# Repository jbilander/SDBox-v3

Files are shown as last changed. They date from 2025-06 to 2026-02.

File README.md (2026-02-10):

# SDBox-v3
A parallel to Pico 2 W and sd-card project for the Amiga

***

Firmware for this project with support for a blinking activity LED can be built from source here:<br />
https://github.com/jbilander/amiga-par-to-spi-adapter/tree/master/rp2350

***

<a href="images/SDBox-v3_pic5.png">
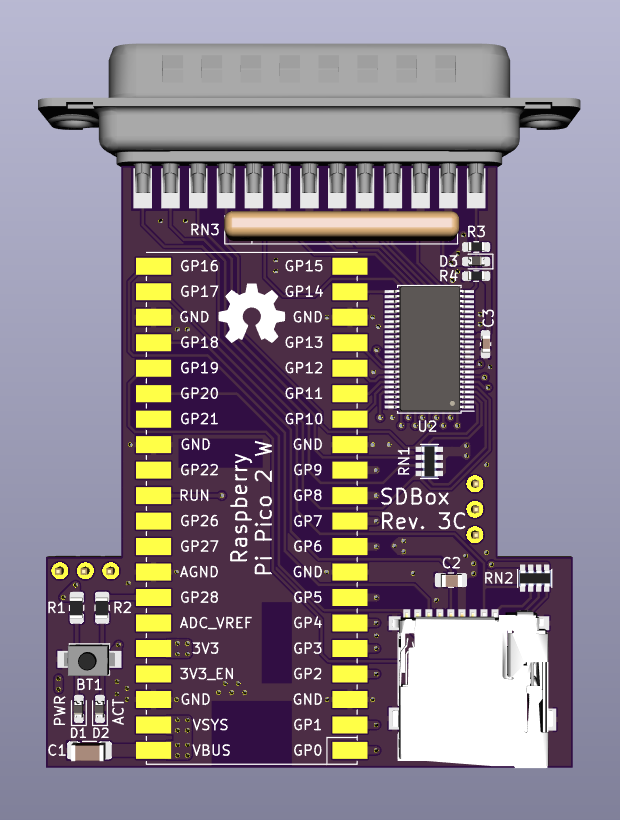
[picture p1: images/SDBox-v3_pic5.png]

</a>
<a href="images/SDBox-v3_pic6.png">
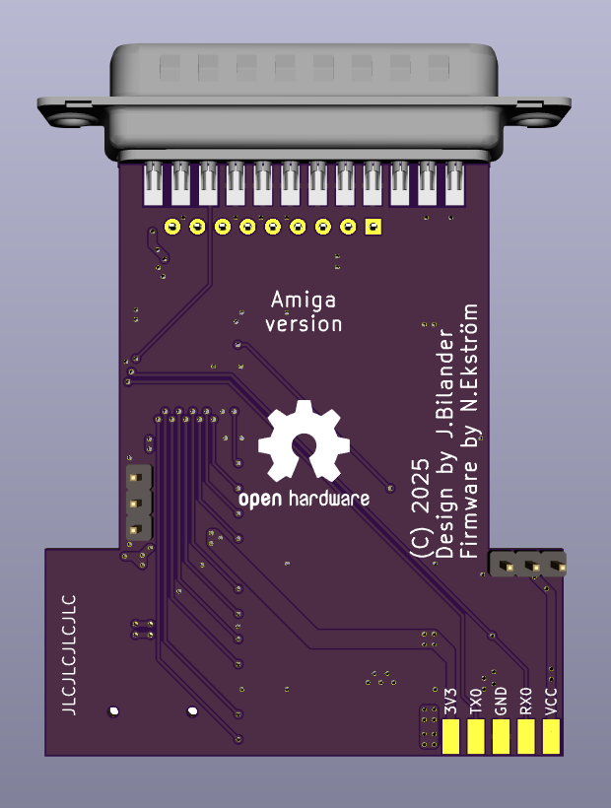
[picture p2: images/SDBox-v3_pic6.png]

</a>

***

<a href="images/SDBox-v3_pic1.jpg">
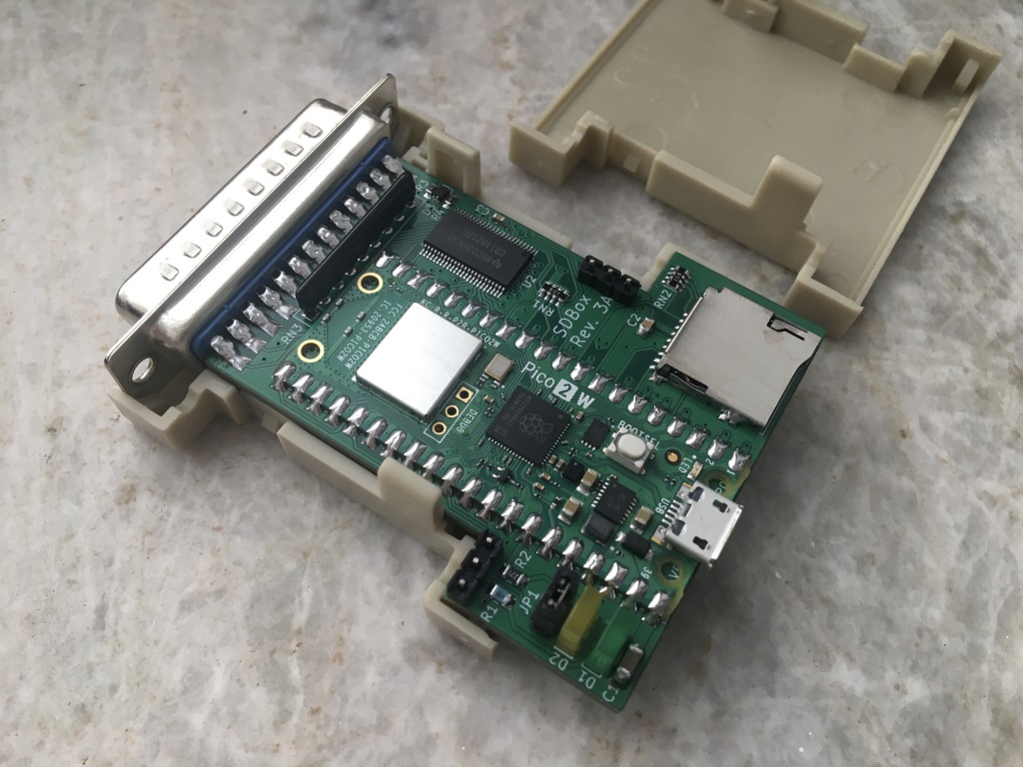
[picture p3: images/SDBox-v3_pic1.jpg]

</a>

***

<a href="images/SDBox-v3_pic2.jpg">
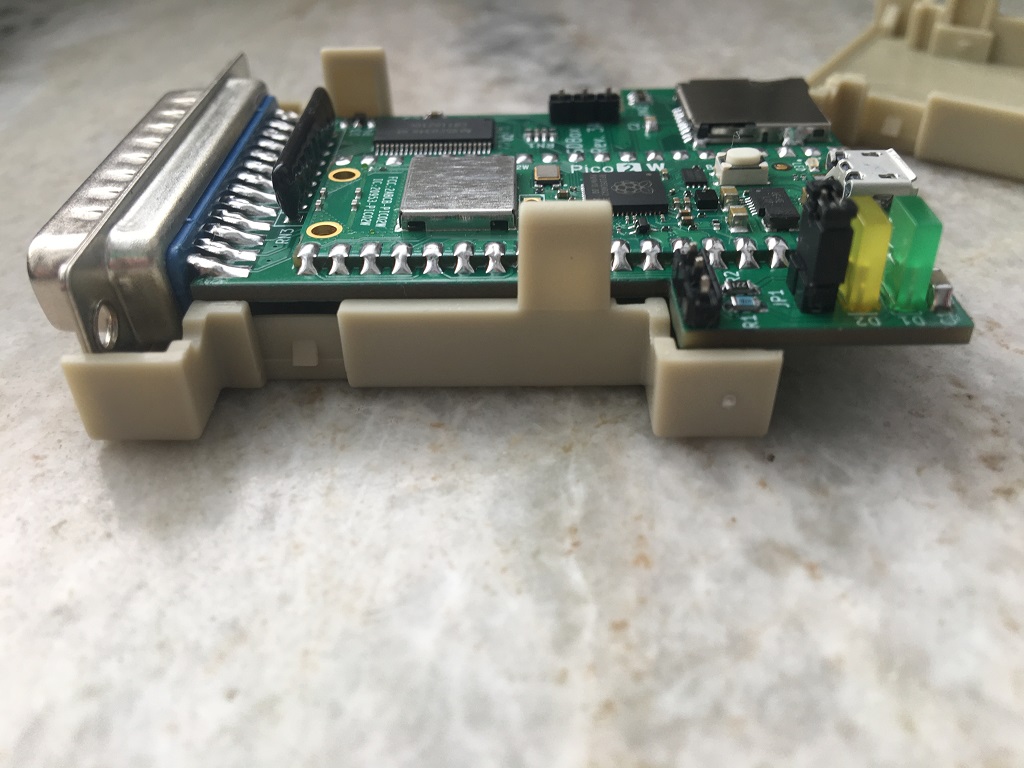
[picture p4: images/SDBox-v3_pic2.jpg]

</a>
<a href="images/SDBox-v3_pic3.jpg">
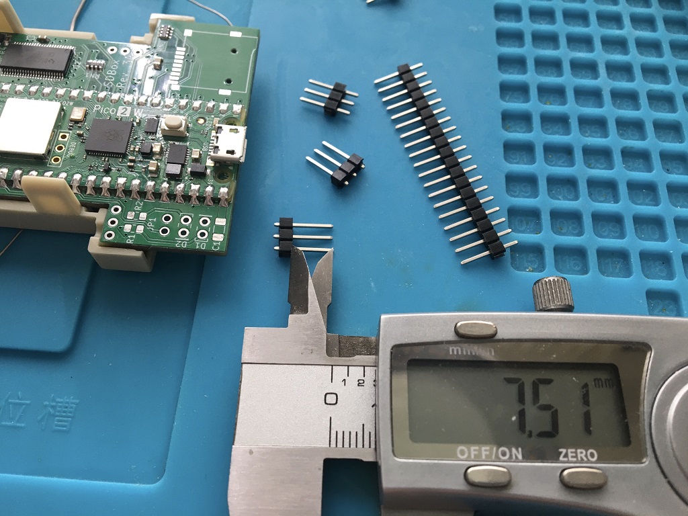
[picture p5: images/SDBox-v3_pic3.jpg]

</a>
<a href="images/SDBox-v3_pic4.jpg">
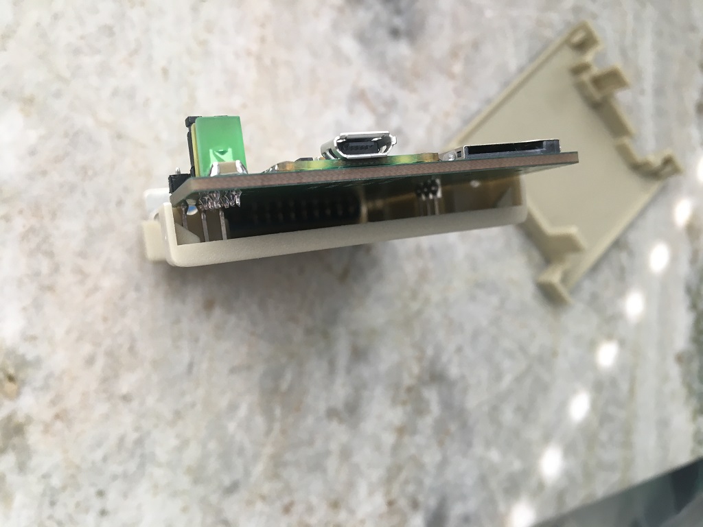
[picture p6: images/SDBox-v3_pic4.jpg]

</a>

***
BOM Rev. 3C
---------
same as 3B but with these changes:
Reference  | Name/Value   | Package | Notes
-|-|-|-|
BT1 | Push button | Sunrom_Tactile_Switch_3x4x2mm_SMD_2-Pin | [Aliexpress](https://www.aliexpress.com/item/4001107238344.html)
D1-D2 (Optional) | SMD LED | 0603 | [Aliexpress](https://www.aliexpress.com/item/1005003836509392.html)
R1 (Optional) | 1k Ω | 0805 | (Mandatory if D1 populated) Series resistor for D1 LED, adjust R-value to your type of LED and preferred brightness
R2 (Optional) | 1k Ω | 0805 | (Mandatory if D2 populated) Series resistor for D2 LED, adjust R-value to your type of LED and preferred brightness

***

BOM Rev. 3B
---------
Reference  | Name/Value   | Package | Notes
-|-|-|-|
U1 | Raspberry Pi Pico 2 W | SC1633 (without header) | [RPi Pico 2 W](https://www.mouser.com/ProductDetail/358-SC1633)
U2 | SN74CBT16210 | TSSOP-48 6.1x12.5mm_P0.5mm | 20-BIT FET Bus switch with level shifting, high-speed TTL-compatible. [SN74CBT16210CDGGR ](https://www.mouser.com/ProductDetail/595-SN74CBT16210CDGG)
J1 | DB25_Male | DSUB-25_Male_EdgeMount_P2.77mm| DB25 Male [Aliexpress](https://www.aliexpress.com/item/1005006354086316.html)
J2 | Sunrom Micro SD Card Holder | 9-pin Micro SD card slot connector | Sunrom Micro-SD [Aliexpress](https://www.aliexpress.com/item/32802051702.html)
J3 | (Optional) UART0 PinHeader | 5-pin 2.54 mm pitch single row | Optional 5V-tolerant header for UART0 (TX on GP12, RX on GP13) 
JP1 | (Optional) PinHeader/Jumper shunt | 2-pin 2.54 mm pitch single row | Jumper on connects Amiga /RESET signal together with RUN-pin (pin 30) on Pico 2 W, resets pico on Ctrl-A-A
D1 (Optional) | LED Square 2x5x7mm | PinHeader_1x02_P2.54mm_Vertical, pin pitch 2.54 mm | Power LED indicator [Aliexpress](https://www.aliexpress.com/item/1005006220921860.html)
D2 (Optional) | LED Square 2x5x7mm | PinHeader_1x02_P2.54mm_Vertical, pin pitch 2.54 mm | Activity LED indicator [Aliexpress](https://www.aliexpress.com/item/1005006220921860.html)
D3 | MMDL6050T1G Small Signal Switching Diode 200mA | SOD-323 | [MMDL6050T1G](https://www.mouser.com/ProductDetail/863-MMDL6050T1G)
R1 (Optional) | 4.7k Ω | 0805 | (Mandatory if D1 populated) Series resistor for D1 LED, adjust R-value to your type of LED and preferred brightness
R2 (Optional) | 220 Ω | 0805 | (Mandatory if D2 populated) Series resistor for D2 LED, adjust R-value to your type of LED and preferred brightness
R3 (Optional) | 10k Ω | 0603 | Pull-up for /STROBE signal, not currently used
R4 | 2.9k - 3k Ω | 0603 | Resistor for dummy loading D3 to achieve steady 0.6-0.7V VCC drop resulting in ~4.3V power supply to U2 [CR0603-FX-2941ELF](https://www.mouser.com/ProductDetail/652-CR0603FX-2941ELF)
RN1, RN2 | CAY16-103J4LF RES ARRAY 4 Resistors 10k Ω | 1206 | [CAY16-103J4LF](https://www.mouser.com/ProductDetail/652-CAY16-103J4LF)
RN3 | A103J | Bussed Resistor Network Array SIP-9 | Pull-up resistors for data lines, 9PIN-10K [Aliexpress](https://www.aliexpress.com/item/1005006954621214.html)
C1 | Capacitor 10uF | 1206 | 
C2 | Capacitor 0.1uF = 100nF | 0805 | 
C3 | Capacitor 0.1uF = 100nF | 0603 |
Housing | 2 x Plastic Shell Cover | For DB25 plug | [Aliexpress](https://www.aliexpress.com/item/1005004717091904.html)
2 x PinHeader | PinHeader Board Weight/Level Support | 3-pin 2.54 mm pitch single row | Move the plastic guard to leave ~7.5 mm of pin before soldering in order to hold board in perfect level

***

When ordering from JLCPCB select:

Specify Layer Sequence: Yes

    L1(Top layer):    F_Cu.gbr
    L2(Inner layer1): GND_Cu.gbr
    L3(Inner layer2): VCC_Cu.gbr
    L4(Bottom layer): B_Cu.gbr

Remove Order Number: 

    Specify a location

This will notify JLC where to put the order number, they will replace the "JLCJLCJLCJLC" silkscreen label.

***

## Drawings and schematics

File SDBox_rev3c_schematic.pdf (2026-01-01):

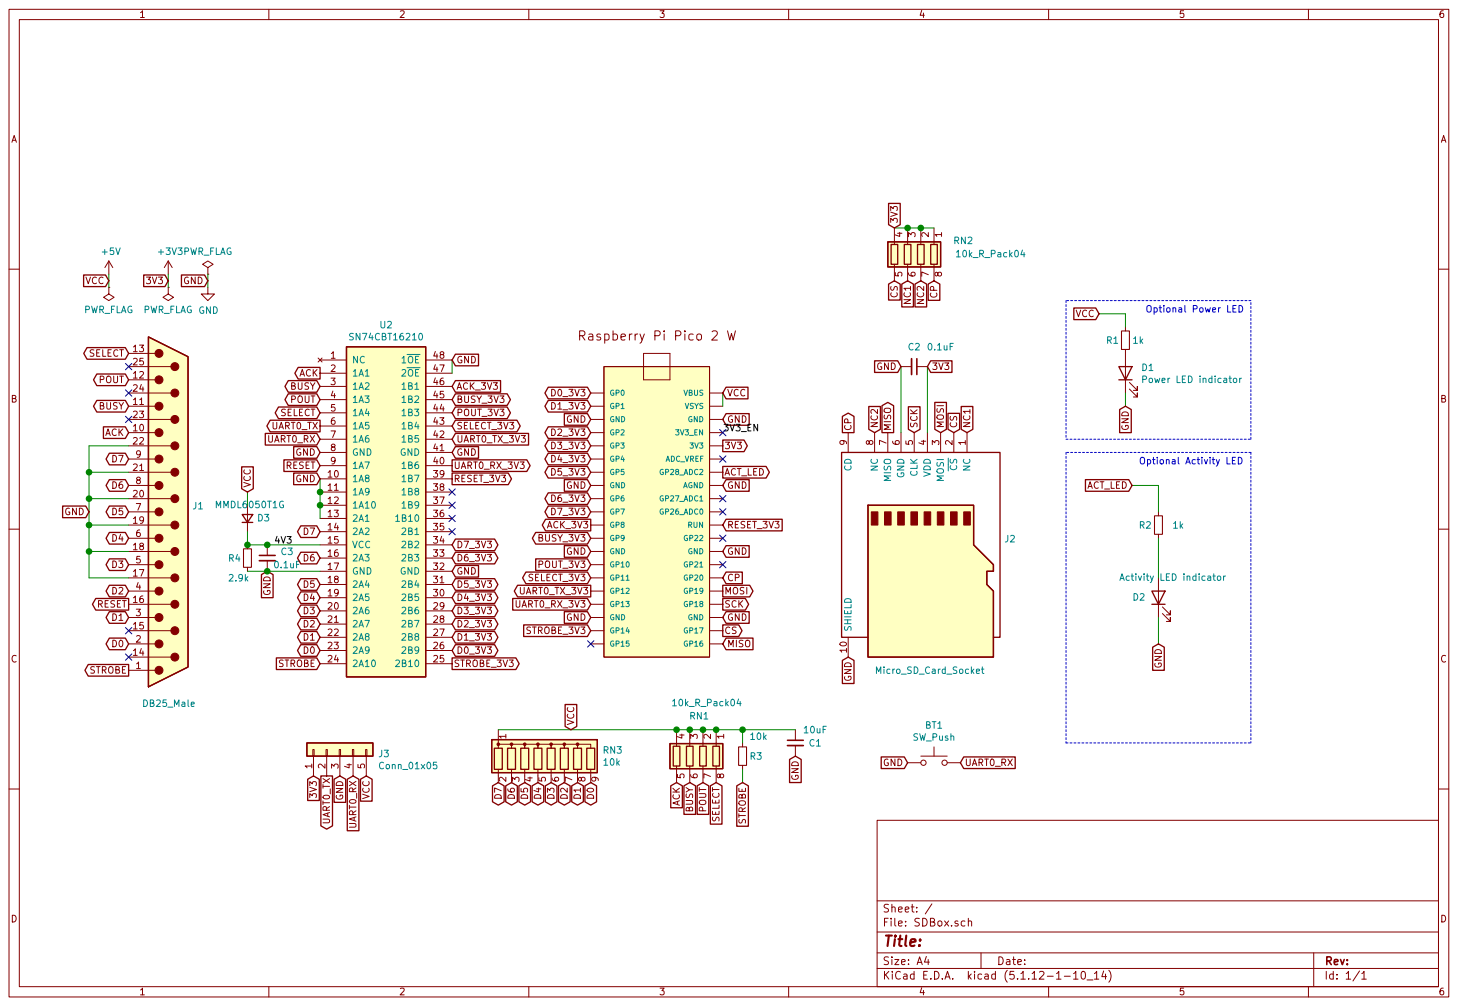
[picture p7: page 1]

Id: 1/1 Title: File: SDBox.sch Sheet: / BT1 SW_Push

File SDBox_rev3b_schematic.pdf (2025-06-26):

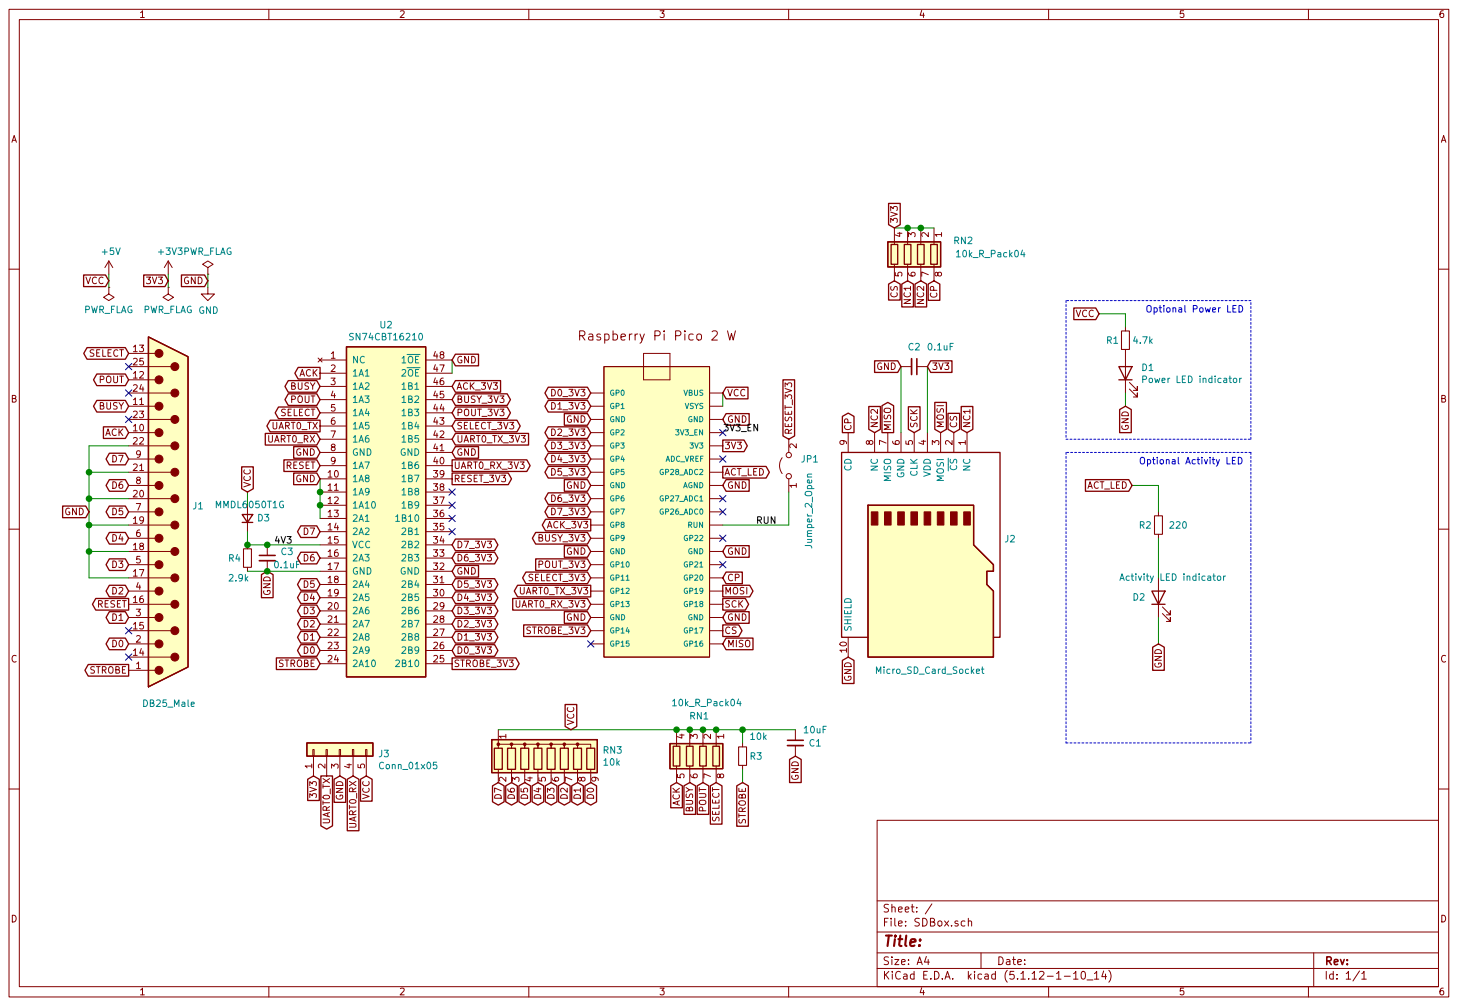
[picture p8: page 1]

Id: 1/1 Title: File: SDBox.sch Sheet: / 1

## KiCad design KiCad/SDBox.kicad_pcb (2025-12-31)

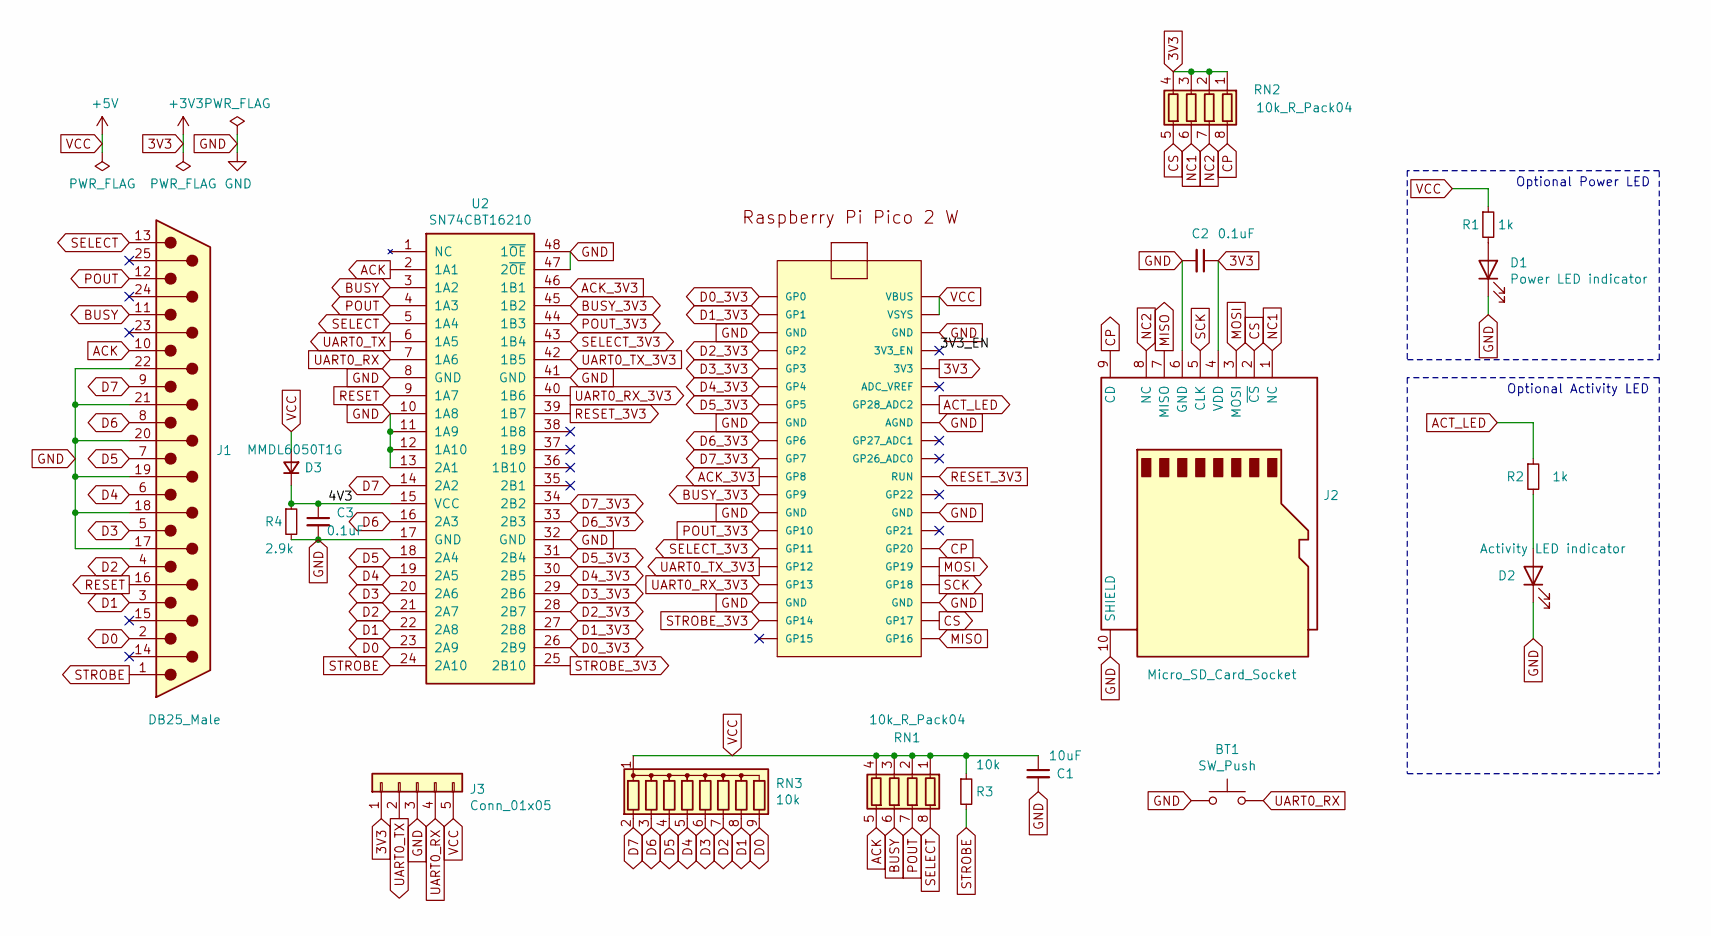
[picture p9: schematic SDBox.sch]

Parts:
BT1: SW_Push; Sunrom_Tactile_Switch_3x4x2mm_SMD_2-Pin
C1: 10uF; C_1206_3216Metric_Pad1.33x1.80mm_HandSolder
C2: 0.1uF; C_0805_2012Metric_Pad1.15x1.40mm_HandSolder
C3: 0.1uF; C_0603_1608Metric_Pad1.08x0.95mm_HandSolder
D1: Power LED indicator; D_0603_1608Metric_Pad1.05x0.95mm_HandSolder
D2: Activity LED indicator; D_0603_1608Metric_Pad1.05x0.95mm_HandSolder
D3: MMDL6050T1G; D_0603_1608Metric_Pad1.05x0.95mm_HandSolder
J1: DB25_Male; DSUB-25_Male_EdgeMount_P2.77mm
J2: Micro_SD_Card_Socket; GCT-MEM2055-00-190-01-A
J3: Conn_01x05; UART_PinHeader_SMD_pads_2.54mm_pitch
R1, R2: 1k; R_0805_2012Metric_Pad1.15x1.40mm_HandSolder
R3: 10k; R_0603_1608Metric_Pad0.98x0.95mm_HandSolder
R4: 2.9k; R_0603_1608Metric_Pad0.98x0.95mm_HandSolder
RN1, RN2: 10k_R_Pack04; RESCAF80P320X160X60-8N
RN3: 10k; R_Array_SIP9
U1: Rapberry_Pi_Pico_2W; RPi_Pico_SMD
U2: SN74CBT16210; TSSOP-48_6.1x12.5mm_P0.5mm

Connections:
3V3: C2.1, J2.4 (VDD), J3.1, RN2.1 (R1.1), RN2.2 (R2.1), RN2.3 (R3.1), RN2.4 (R4.1), U1.36 (3V3)
/3V3_EN: U1.37 (3V3_EN)
/4V3: C3.1, D3.1 (K), R4.1, U2.15 (VCC)
ACK: J1.10, RN1.5 (R4.2), U2.2 (1A1)
ACK_3V3: U1.11 (GP8), U2.46 (1B1)
ACT_LED: R2.1, U1.34 (GP28_ADC2)
BUSY: J1.11, RN1.6 (R3.2), U2.3 (1A2)
BUSY_3V3: U1.12 (GP9), U2.45 (1B2)
CP: J2.9 (CD), RN2.8 (R1.2), U1.26 (GP20)
CS: J2.2 (~CS), RN2.5 (R4.2), U1.22 (GP17)
D0: J1.2, RN3.9 (R8), U2.23 (2A9)
D0_3V3: U1.1 (GP0), U2.26 (2B9)
D1: J1.3, RN3.8 (R7), U2.22 (2A8)
D1_3V3: U1.2 (GP1), U2.27 (2B8)
D2: J1.4, RN3.7 (R6), U2.21 (2A7)
D2_3V3: U1.4 (GP2), U2.28 (2B7)
D3: J1.5, RN3.6 (R5), U2.20 (2A6)
D3_3V3: U1.5 (GP3), U2.29 (2B6)
D4: J1.6, RN3.5 (R4), U2.19 (2A5)
D4_3V3: U1.6 (GP4), U2.30 (2B5)
D5: J1.7, RN3.4 (R3), U2.18 (2A4)
D5_3V3: U1.7 (GP5), U2.31 (2B4)
D6: J1.8, RN3.3 (R2), U2.16 (2A3)
D6_3V3: U1.9 (GP6), U2.33 (2B3)
D7: J1.9, RN3.2 (R1), U2.14 (2A2)
D7_3V3: U1.10 (GP7), U2.34 (2B2)
GND: BT1.1, C1.2, C2.2, C3.2, D1.1 (K), D2.1 (K), J1.17, J1.18, J1.19, J1.20, J1.21, J1.22, J2.6 (GND), J2.10 (SHIELD), J3.3, R4.2, U1.3 (GND), U1.8 (GND), U1.13 (GND), U1.18 (GND), U1.23 (GND), U1.28 (GND), U1.33 (AGND), U1.38 (GND), U2.8 (GND), U2.10 (1A8), U2.11 (1A9), U2.12 (1A10), U2.13 (2A1), U2.17 (GND), U2.32 (GND), U2.41 (GND), U2.47 (2~OE), U2.48 (1~OE)
MISO: J2.7 (MISO), U1.21 (GP16)
MOSI: J2.3 (MOSI), U1.25 (GP19)
NC1: J2.1 (NC), RN2.6 (R3.2)
NC2: J2.8 (NC), RN2.7 (R2.2)
unnamed: D1.2 (A), R1.2
unnamed: D2.2 (A), R2.2
POUT: J1.12, RN1.7 (R2.2), U2.4 (1A3)
POUT_3V3: U1.14 (GP10), U2.44 (1B3)
RESET: J1.16, U2.9 (1A7)
RESET_3V3: U1.30 (RUN), U2.39 (1B7)
SCK: J2.5 (CLK), U1.24 (GP18)
SELECT: J1.13, RN1.8 (R1.2), U2.5 (1A4)
SELECT_3V3: U1.15 (GP11), U2.43 (1B4)
STROBE: J1.1, R3.2, U2.24 (2A10)
STROBE_3V3: U1.19 (GP14), U2.25 (2B10)
UART0_RX: BT1.2, J3.4, U2.7 (1A6)
UART0_RX_3V3: U1.17 (GP13), U2.40 (1B6)
UART0_TX: J3.2, U2.6 (1A5)
UART0_TX_3V3: U1.16 (GP12), U2.42 (1B5)
VCC: C1.1, D3.2 (A), J3.5, R1.1, R3.1, RN1.1 (R1.1), RN1.2 (R2.1), RN1.3 (R3.1), RN1.4 (R4.1), RN3.1 (common), U1.39 (VSYS), U1.40 (VBUS)

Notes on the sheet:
Optional Activity LED
Optional Power LED

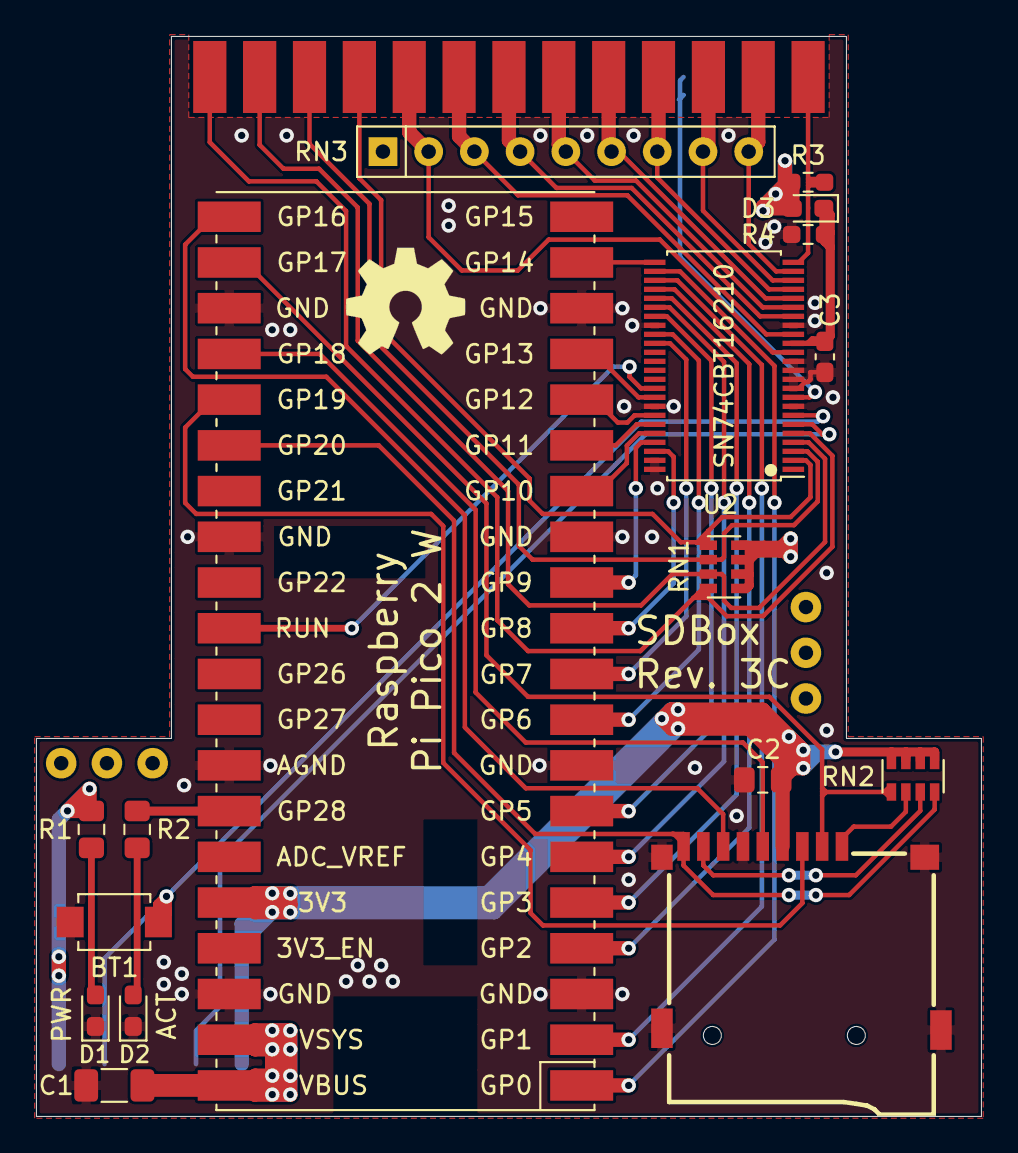
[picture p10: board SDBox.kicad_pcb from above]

Board: 4 copper layers, 52.5 x 60.0 mm, 19 parts (1 on the bottom side), 46 nets.

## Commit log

2025-05-12 Add footprint
2025-05-12 Add KiCad files
    [SDBox.kicad_pcb, SDBox.sch]
2025-05-14 Add Rapberry_Pi_Pico_2W and +5V flag for VCC
2025-05-14 Update board with latest setup
2025-05-14 Update design to accomodate a Rapberry_Pi_Pico_2W
    [SDBox.kicad_pcb, SDBox.sch]
2025-05-14 Place and route R3
    [SDBox.kicad_pcb]
2025-05-15 Add RN3 (pull-ups for data lines), fixed keep-out areas for header and test-points on RPi Pico 2 W
    [SDBox.kicad_pcb, SDBox.sch]
2025-05-15 Change board to four layer
    [SDBox.kicad_pcb]
2025-05-15 Add track width 0.3 mm
2025-05-15 Change U2 SN74CB3T16210 to SN74CBT16210 and add diode D3 and resistor R4 to drop VCC to 4.3V power supply for U2
    [SDBox.kicad_pcb, SDBox.sch]
2025-05-15 Change Micro_SD_Card_Socket drill holes to 1 mm
    [SDBox.kicad_pcb]
2025-05-15 Add UART0_TX and UART0_RX through level shifter
    [SDBox.kicad_pcb, SDBox.sch]
2025-05-15 Improve ground stitching
    [SDBox.kicad_pcb]
2025-05-15 Add UART pinheader on underside with TX0 (GP12), RX0 (GP13) and Power and GND
    [SDBox.kicad_pcb, SDBox.sch]
2025-05-16 Improve routing
    [SDBox.kicad_pcb, SDBox.sch]
2025-05-16 silkscreen fixes
    [SDBox.kicad_pcb]
2025-05-16 Change to correct path (packages3d folder) for SD card slot 3D-model
    [SDBox.kicad_pcb]
2025-05-17 Small fix improved positioning of a GND via and the UART0_RX via
    [SDBox.kicad_pcb]
2025-05-19 Change R1,R2 value from 220 to 330 Ohm, change D3 value from D_small to MMDL6050T1G
    [SDBox.kicad_pcb, SDBox.sch]
2025-05-30 Add two PinHeader_1x03_P2.54mm for support structure, fix of edge cuts for better fit plastic shells
    [SDBox.kicad_pcb]
2025-05-31 Update plot params
    [SDBox.kicad_pcb]
2025-06-26 Extended board 1 mm, moved RN3 0.5 mm on Y-axis and changed hole size on JP1, D1, D2 to 0.8 mm, bumped revision to 3B
    [SDBox.kicad_pcb]
2025-06-26 Change R1 value from 330 to 4.7k, Change R2 value from 330 to 220
    [SDBox.kicad_pcb, SDBox.sch]
2025-06-26 Add schematic pdf
2025-07-12 Small fix moving two GND vias to align with the rest (cosmetic fix)
    [SDBox.kicad_pcb]
2025-12-31 Add push button to GPIO13, remove JP1 and connect /RESET directly to RUN, change to 0603 SMD LED diodes, change resistor values on R1,R2 to 1k Ohm, move J3 to not interfere with USB-cable, bump revis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
    [SDBox.kicad_pcb, SDBox.sch]
